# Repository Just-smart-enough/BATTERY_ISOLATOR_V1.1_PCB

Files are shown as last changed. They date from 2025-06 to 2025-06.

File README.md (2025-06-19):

# BATTERY_ISOLATOR_V1.1_PCB
A prototype 12V RV battery isolator using a STM32F042F6P6 processor, an ACS724 current sensor and a MCP2551 CAN Transceiver.  
Intention is to PWM current flow based on max current parameters and voltage differences between the two batteries. 
It will also broadcast both battery's voltage and the charging current over CANbus

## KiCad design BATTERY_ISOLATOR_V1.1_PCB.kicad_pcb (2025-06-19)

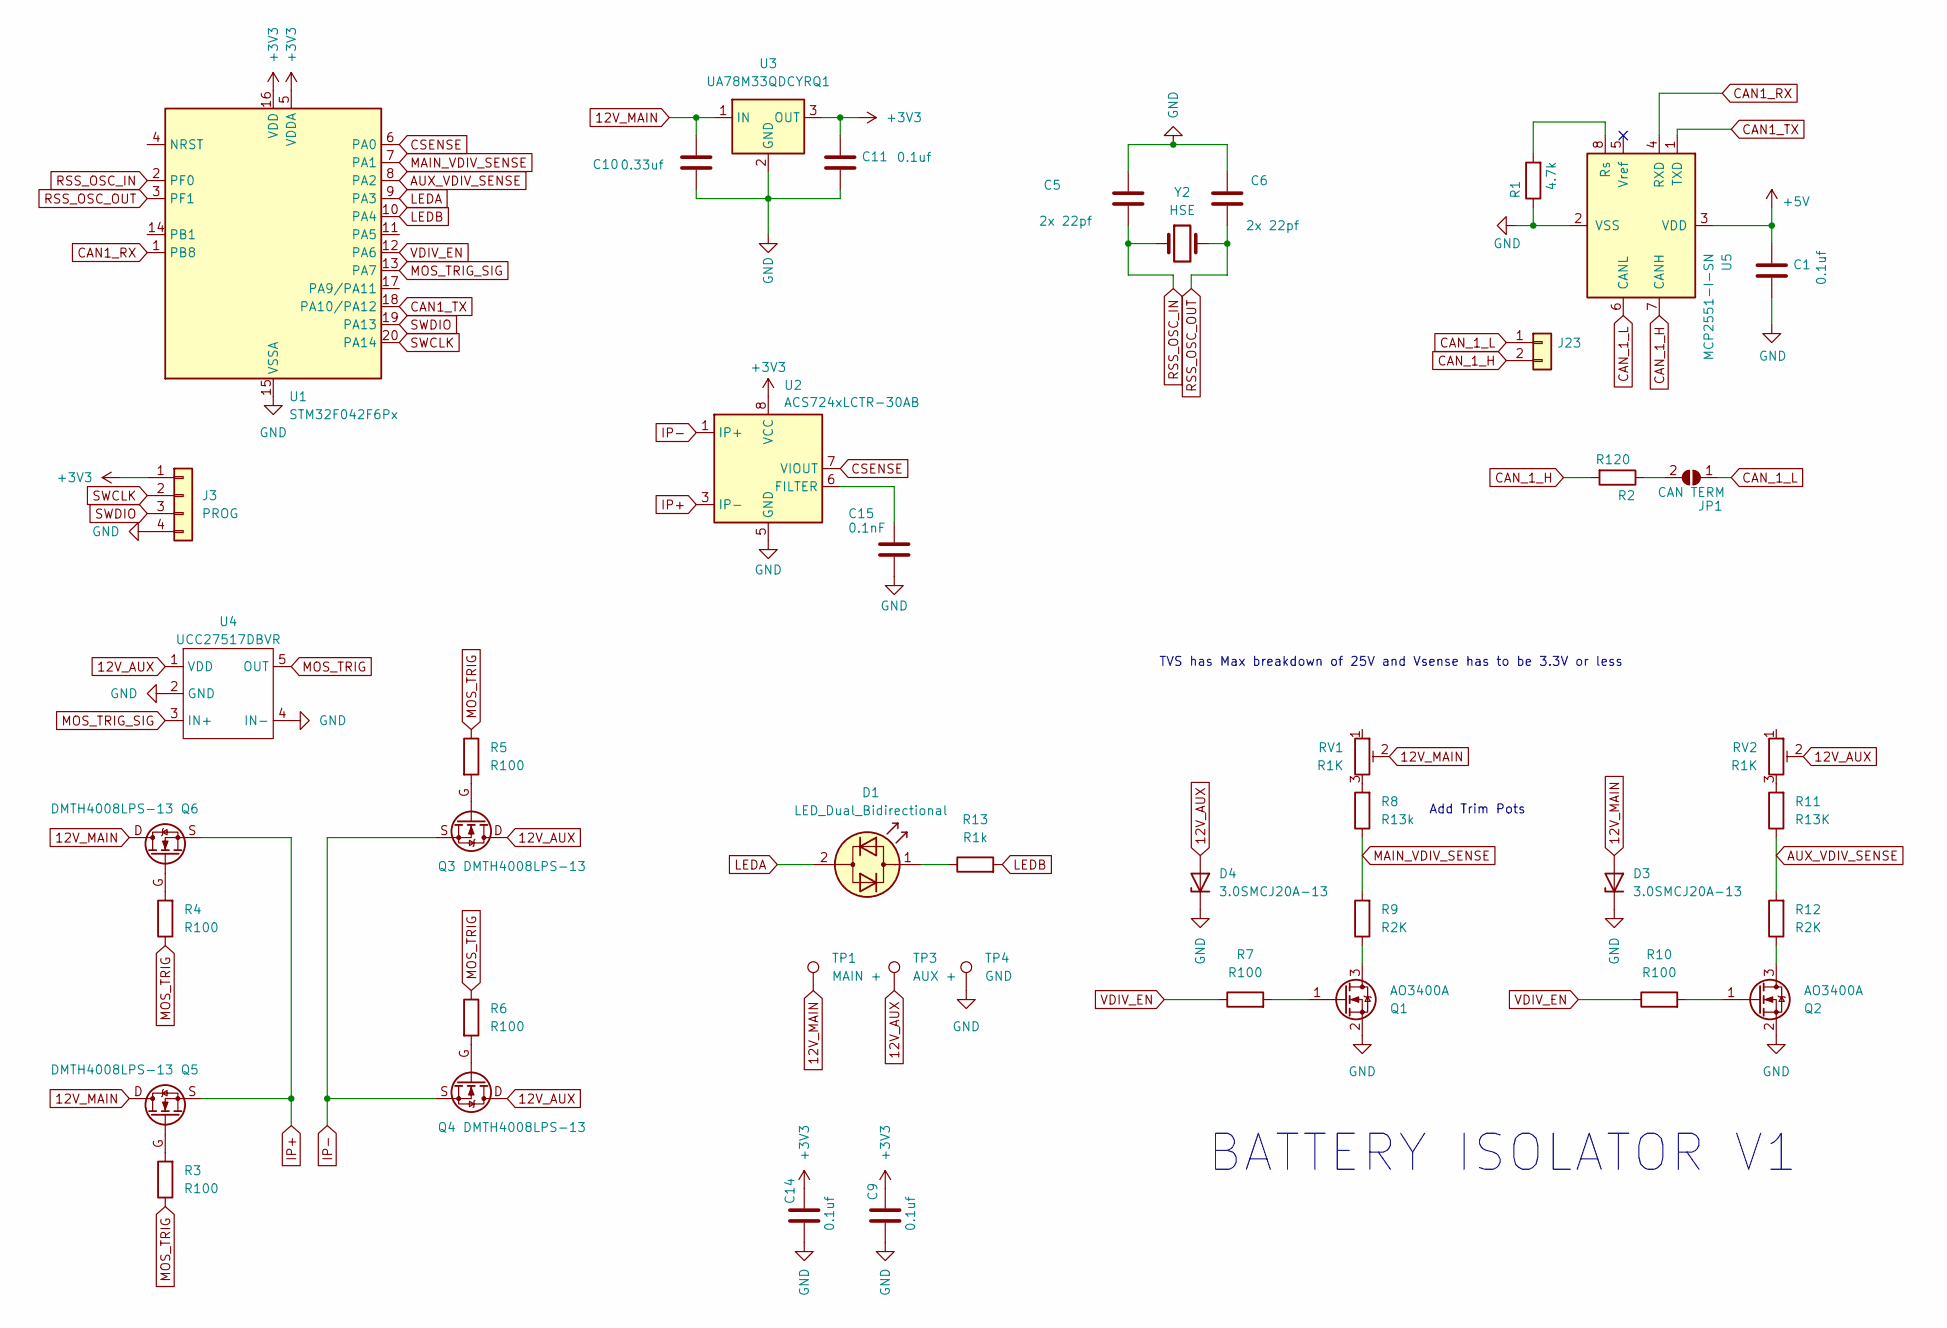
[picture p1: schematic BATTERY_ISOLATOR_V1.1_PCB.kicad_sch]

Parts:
C1: 0.1uf; C_0805_2012Metric
C5, C6: 2x 22pf; C_0805_2012Metric
C9, C11, C14: 0.1uf; C_0603_1608Metric
C10: 0.33uf; C_0603_1608Metric
C15: 0.1nF; C_0402_1005Metric
D1: LED_Dual_Bidirectional; LED_D5.0mm
D3, D4: 3.0SMCJ20A-13; D_SMC
J3: PROG; PinHeader_1x04_P1.27mm_Vertical
J23: CAN 1; JST_XH_B2B-XH-A_1x02_P2.50mm_Vertical
JP1: CAN TERM; PinHeader_1x02_P2.54mm_Vertical
Q1, Q2: AO3400A; SOT-23
Q3, Q4, Q5, Q6: DMTH4008LPS-13; DMTH4008LPS-13(DI5060-8)
R1: 4.7k; R_0603_1608Metric
R2: R120; R_0603_1608Metric
R3, R4, R5, R6, R7, R10: R100; R_0603_1608Metric
R8: R13k; R_0603_1608Metric
R9, R12: R2K; R_0603_1608Metric
R11: R13K; R_0603_1608Metric
R13: R1k; R_0603_1608Metric
RV1, RV2: R1K; Potentiometer_Bourns_TC33X_Vertical
TP1: MAIN +; SAMZO 8060500M4
TP3: AUX +; SAMZO 8060500M4
TP4: GND; SAMZO 8060500M4
U1: STM32F042F6Px; TSSOP-20_4.4x6.5mm_P0.65mm
U2: ACS724xLCTR-30AB; SOIC-8_3.9x4.9mm_P1.27mm
U3: UA78M33QDCYRQ1; SOT-223-3_TabPin2
U4: UCC27517DBVR; SOT-23-5
U5: MCP2551-I-SN; SOIC-8_3.9x4.9mm_P1.27mm
Y2: HSE; Crystal_SMD_5032-2Pin_5.0x3.2mm

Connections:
12V_AUX: D4.2 (A), Q3.D, Q4.D, RV2.2, TP3.1, U4.1 (VDD)
12V_MAIN: C10.1, D3.2 (A), Q5.D, Q6.D, RV1.2, TP1.1, U3.1 (IN)
+3V3: C9.1, C11.1, C14.1, J3.1, U1.5 (VDDA), U1.16 (VDD), U2.8 (VCC), U3.3 (OUT)
+5V: C1.1, U5.3 (VDD)
AUX_VDIV_SENSE: R11.1, R12.2, U1.8 (PA2)
CAN1_RX: U1.1 (PB8), U5.4 (RXD)
CAN1_TX: U1.18 (PA10/PA12), U5.1 (TXD)
CAN_1_H: J23.2, R2.2, U5.7 (CANH)
CAN_1_L: J23.1, JP1.1 (A), U5.6 (CANL)
CSENSE: U1.6 (PA0), U2.7 (VIOUT)
GND: C1.2, C5.1, C6.1, C9.2, C10.2, C11.2, C14.2, C15.2, D3.1 (K), D4.1 (K), J3.4, Q1.2 (S), Q2.2 (S), R1.1, TP4.1, U1.15 (VSSA), U2.5 (GND), U3.2 (GND), U4.2 (GND), U4.4 (IN-), U5.2 (VSS)
IP+: Q5.S, Q6.S, U2.3 (IP-), U2.4 (IP-)
IP-: Q3.S, Q4.S, U2.1 (IP+), U2.2 (IP+)
LEDA: D1.2 (AK), U1.9 (PA3)
LEDB: R13.2, U1.10 (PA4)
MAIN_VDIV_SENSE: R8.1, R9.2, U1.7 (PA1)
MOS_TRIG: R3.1, R4.1, R5.1, R6.1, U4.5 (OUT)
MOS_TRIG_SIG: U1.13 (PA7), U4.3 (IN+)
unnamed: D1.1 (KA), R13.1
unnamed: JP1.2 (B), R2.1
unnamed: Q1.3 (D), R9.1
unnamed: Q1.1 (G), R7.2
unnamed: Q2.3 (D), R12.1
unnamed: Q2.1 (G), R10.2
unnamed: Q3.G, R5.2
unnamed: Q4.G, R6.2
unnamed: Q5.G, R3.2
unnamed: Q6.G, R4.2
unnamed: R8.2, RV1.3
unnamed: R11.2, RV2.3
unnamed: C15.1, U2.6 (FILTER)
unnamed: R1.2, U5.8 (Rs)
RSS_OSC_IN: C5.2, U1.2 (PF0), Y2.1
RSS_OSC_OUT: C6.2, U1.3 (PF1), Y2.2
SWCLK: J3.2, U1.20 (PA14)
SWDIO: J3.3, U1.19 (PA13)
VDIV_EN: R7.1, R10.1, U1.12 (PA6)

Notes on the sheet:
BATTERY ISOLATOR V1
TVS has Max breakdown of 25V and Vsense has to be 3.3V or less
Add Trim Pots

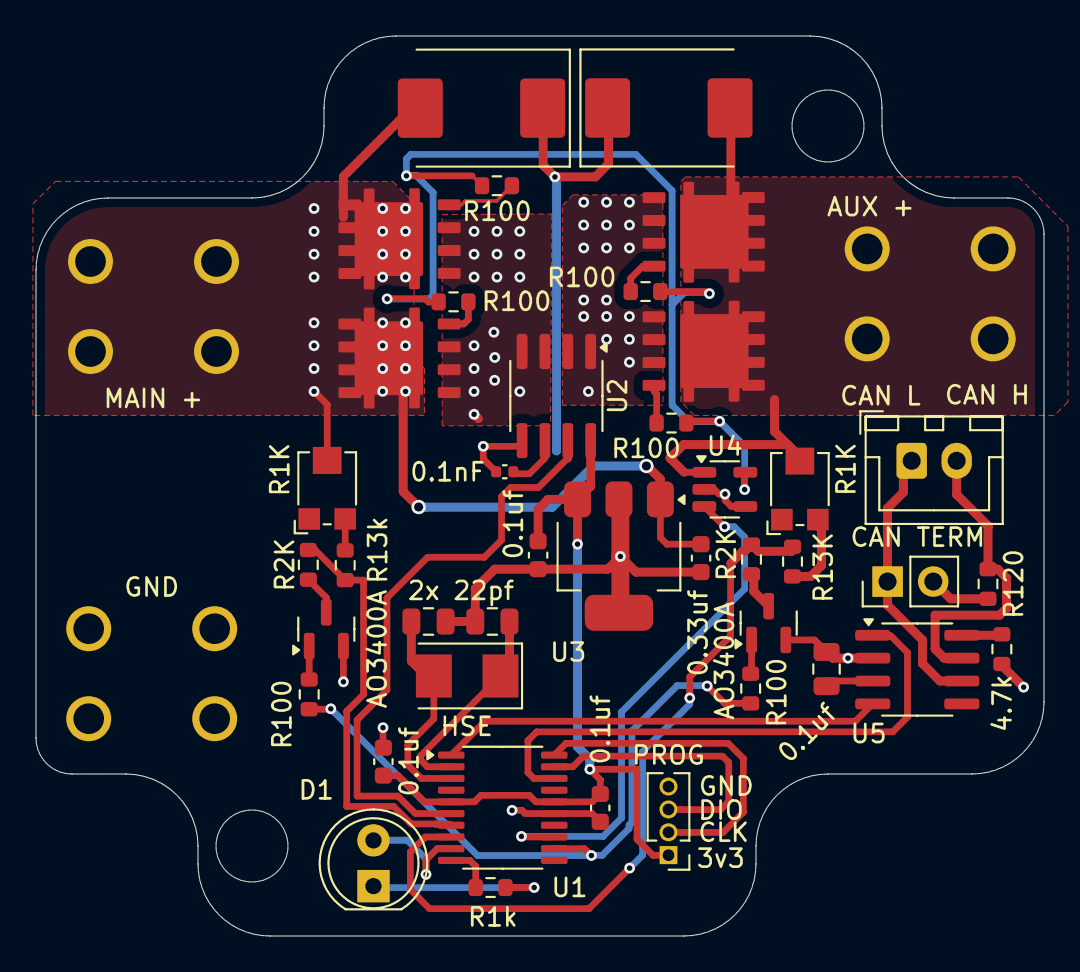
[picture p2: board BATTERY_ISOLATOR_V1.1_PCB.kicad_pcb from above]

Board: 2 copper layers, 56.0 x 50.0 mm, 44 parts (0 on the bottom side), 37 nets.

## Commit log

2025-06-17 Updated files
    Added initial schematic and layout
    [BATTERY_ISOLATOR_V1.1_PCB.kicad_pcb, BATTERY_ISOLATOR_V1.1_PCB.kicad_sch, CALCS.xlsx]
2025-06-19 Added bicolor LED and Switch 3V3 source to 12V Main
    [BATTERY_ISOLATOR_V1.1_PCB.kicad_pcb, BATTERY_ISOLATOR_V1.1_PCB.kicad_sch]
